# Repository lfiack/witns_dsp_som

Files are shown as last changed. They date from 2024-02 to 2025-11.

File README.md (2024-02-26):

# DSP System on Module from WITNS

## Make the project work
This project uses a submodule for the KiCAD library. To get it properly, use the `--recursive` option when cloning the repo :

```bash
git clone --recursive git@github.com:lfiack/witns_dsp_som
```

If you forgot the `--recursive` option (as I do quite often), you can type the following command :

```bash
git submodule update --init --recursive
```

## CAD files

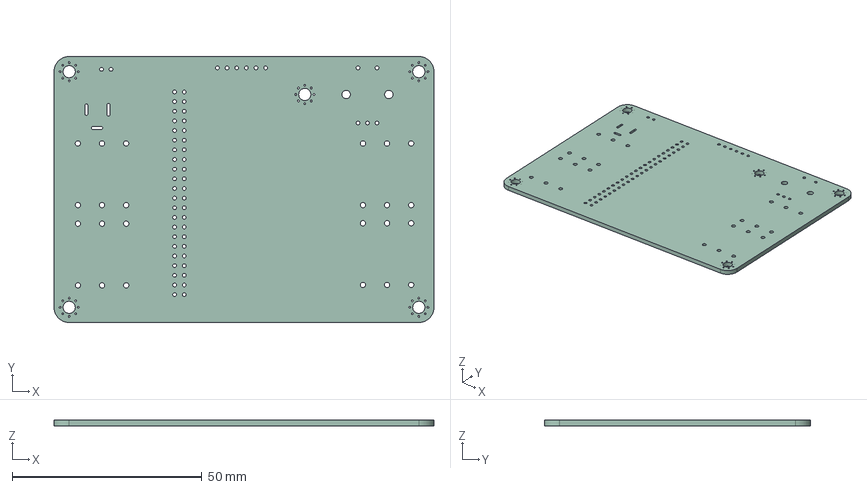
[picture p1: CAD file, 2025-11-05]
hardware/carry/carry/carry.step
100.0 x 70.0 x 1.51 mm

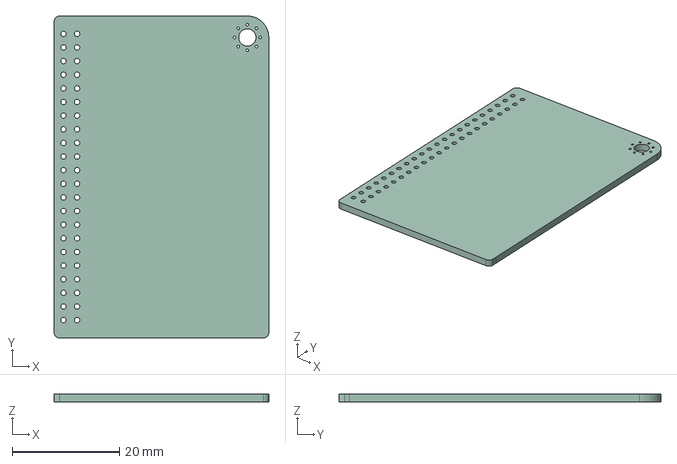
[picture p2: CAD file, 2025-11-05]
hardware/dsp_som/dsp_som.step
40.0 x 60.0 x 1.47 mm

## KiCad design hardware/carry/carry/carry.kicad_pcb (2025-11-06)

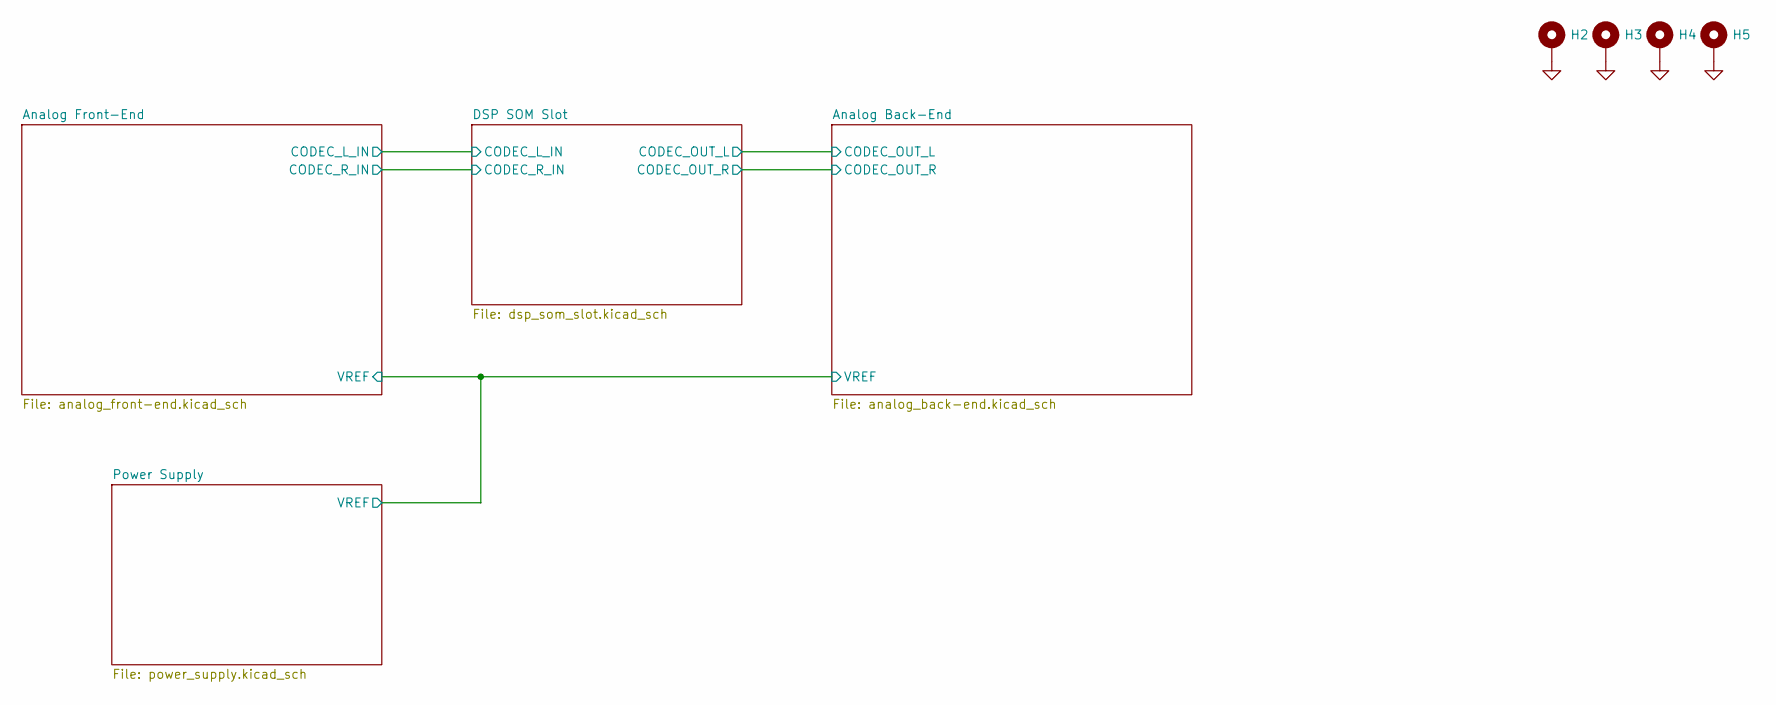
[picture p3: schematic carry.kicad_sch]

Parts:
H2, H3, H4, H5: MountingHole_Pad; MountingHole_3.2mm_M3_Pad_Via

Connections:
GND: H2.1, H3.1, H4.1, H5.1; also elsewhere on the board

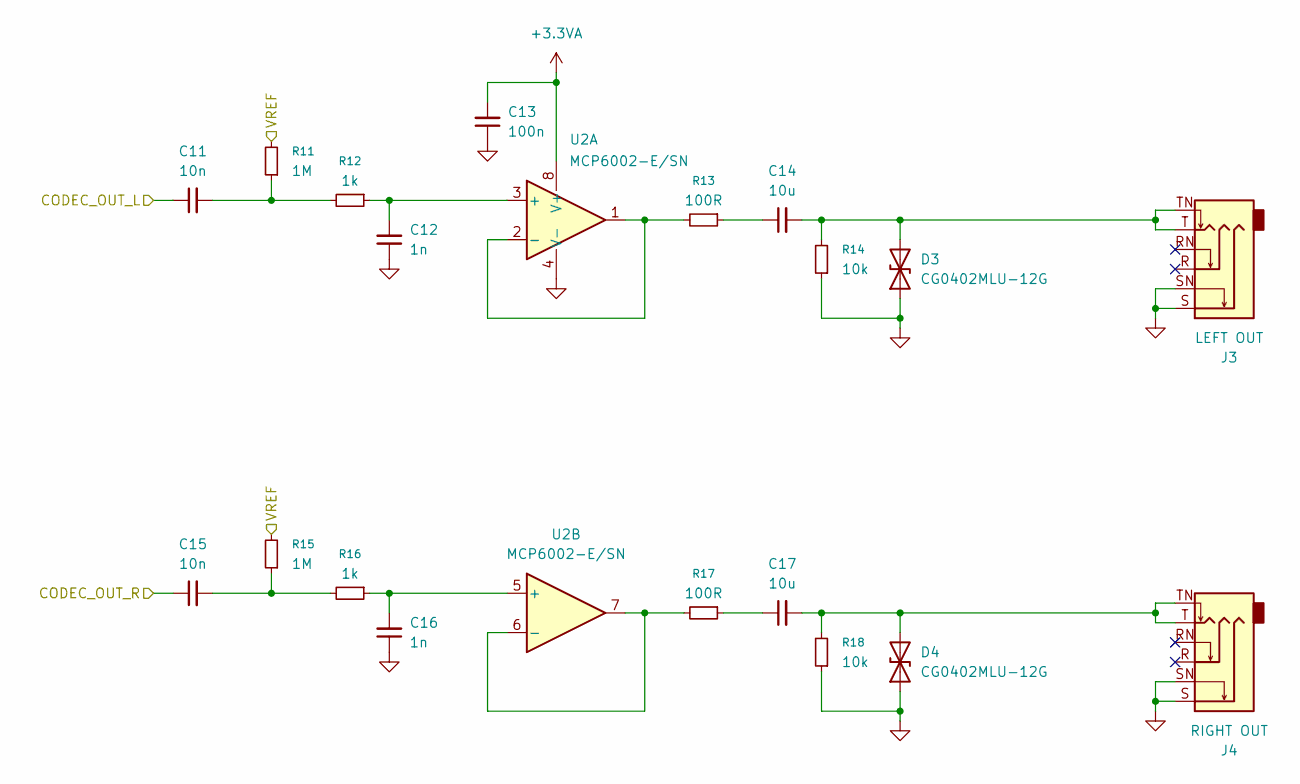
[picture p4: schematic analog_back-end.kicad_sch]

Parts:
C11, C15: 10n; C_0603_1608Metric
C12, C16: 1n; C_0603_1608Metric
C13: 100n; C_0603_1608Metric
C14, C17: 10u; C_0603_1608Metric
D3, D4: CG0402MLU-12G; D_0402_1005Metric
J3: LEFT OUT; Jack_6.35mm_Neutrik_NMJ6HCD3_Horizontal
J4: RIGHT OUT; Jack_6.35mm_Neutrik_NMJ6HCD3_Horizontal
R11, R15: 1M; R_0603_1608Metric
R12, R16: 1k; R_0603_1608Metric
R13, R17: 100R; R_0603_1608Metric
R14, R18: 10k; R_0603_1608Metric
U2: MCP6002-E/SN; SOIC-8_3.9x4.9mm_P1.27mm

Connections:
+3.3VA: C13.2, U2.8 (V+); also elsewhere on the board
/Analog Back-End/CODEC_OUT_L: C11.1; also elsewhere on the board
/Analog Back-End/CODEC_OUT_R: C15.1; also elsewhere on the board
/Analog Back-End/VREF: R11.2, R15.2; also elsewhere on the board
GND: C12.1, C13.1, C16.1, D3.1 (A1), D4.1 (A1), J3.S, J3.SN, J4.S, J4.SN, R14.1, R18.1, U2.4 (V-); also elsewhere on the board
unnamed: C11.2, R11.1, R12.2
unnamed: C14.1, R13.1
unnamed: C15.2, R15.1, R16.2
unnamed: C17.1, R17.1
unnamed: C14.2, D3.2 (A2), J3.T, J3.TN, R14.2
unnamed: C17.2, D4.2 (A2), J4.T, J4.TN, R18.2
unnamed: C12.2, R12.1, U2.3 (+)
unnamed: R13.2, U2.1, U2.2 (-)
unnamed: C16.2, R16.1, U2.5 (+)
unnamed: R17.2, U2.6 (-), U2.7

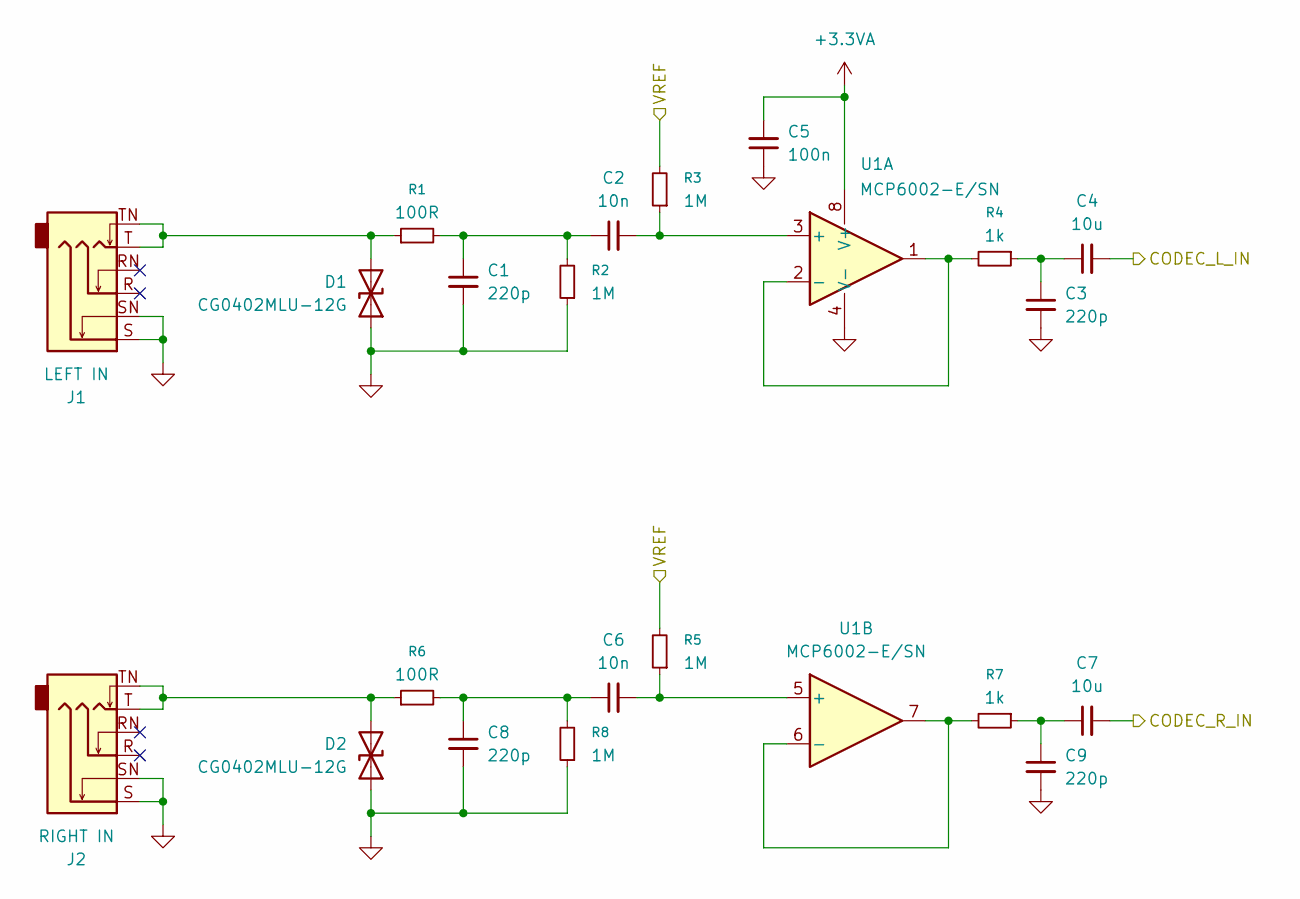
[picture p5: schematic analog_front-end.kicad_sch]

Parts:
C1, C3, C8, C9: 220p; C_0603_1608Metric
C2, C6: 10n; C_0603_1608Metric
C4, C7: 10u; C_0603_1608Metric
C5: 100n; C_0603_1608Metric
D1, D2: CG0402MLU-12G; D_0402_1005Metric
J1: LEFT IN; Jack_6.35mm_Neutrik_NMJ6HCD3_Horizontal
J2: RIGHT IN; Jack_6.35mm_Neutrik_NMJ6HCD3_Horizontal
R1, R6: 100R; R_0603_1608Metric
R2, R3, R5, R8: 1M; R_0603_1608Metric
R4, R7: 1k; R_0603_1608Metric
U1: MCP6002-E/SN; SOIC-8_3.9x4.9mm_P1.27mm

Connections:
+3.3VA: C5.2, U1.8 (V+); also elsewhere on the board
/Analog Back-End/VREF: R3.2, R5.2; also elsewhere on the board
/Analog Front-End/CODEC_L_IN: C4.2; also elsewhere on the board
/Analog Front-End/CODEC_R_IN: C7.2; also elsewhere on the board
GND: C1.2, C3.2, C5.1, C8.2, C9.2, D1.1 (A1), D2.1 (A1), J1.S, J1.SN, J2.S, J2.SN, R2.1, R8.1, U1.4 (V-); also elsewhere on the board
unnamed: C1.1, C2.1, R1.2, R2.2
unnamed: C3.1, C4.1, R4.1
unnamed: C6.1, C8.1, R6.2, R8.2
unnamed: C7.1, C9.1, R7.1
unnamed: D1.2 (A2), J1.T, J1.TN, R1.1
unnamed: D2.2 (A2), J2.T, J2.TN, R6.1
unnamed: C2.2, R3.1, U1.3 (+)
unnamed: R4.2, U1.1, U1.2 (-)
unnamed: C6.2, R5.1, U1.5 (+)
unnamed: R7.2, U1.6 (-), U1.7

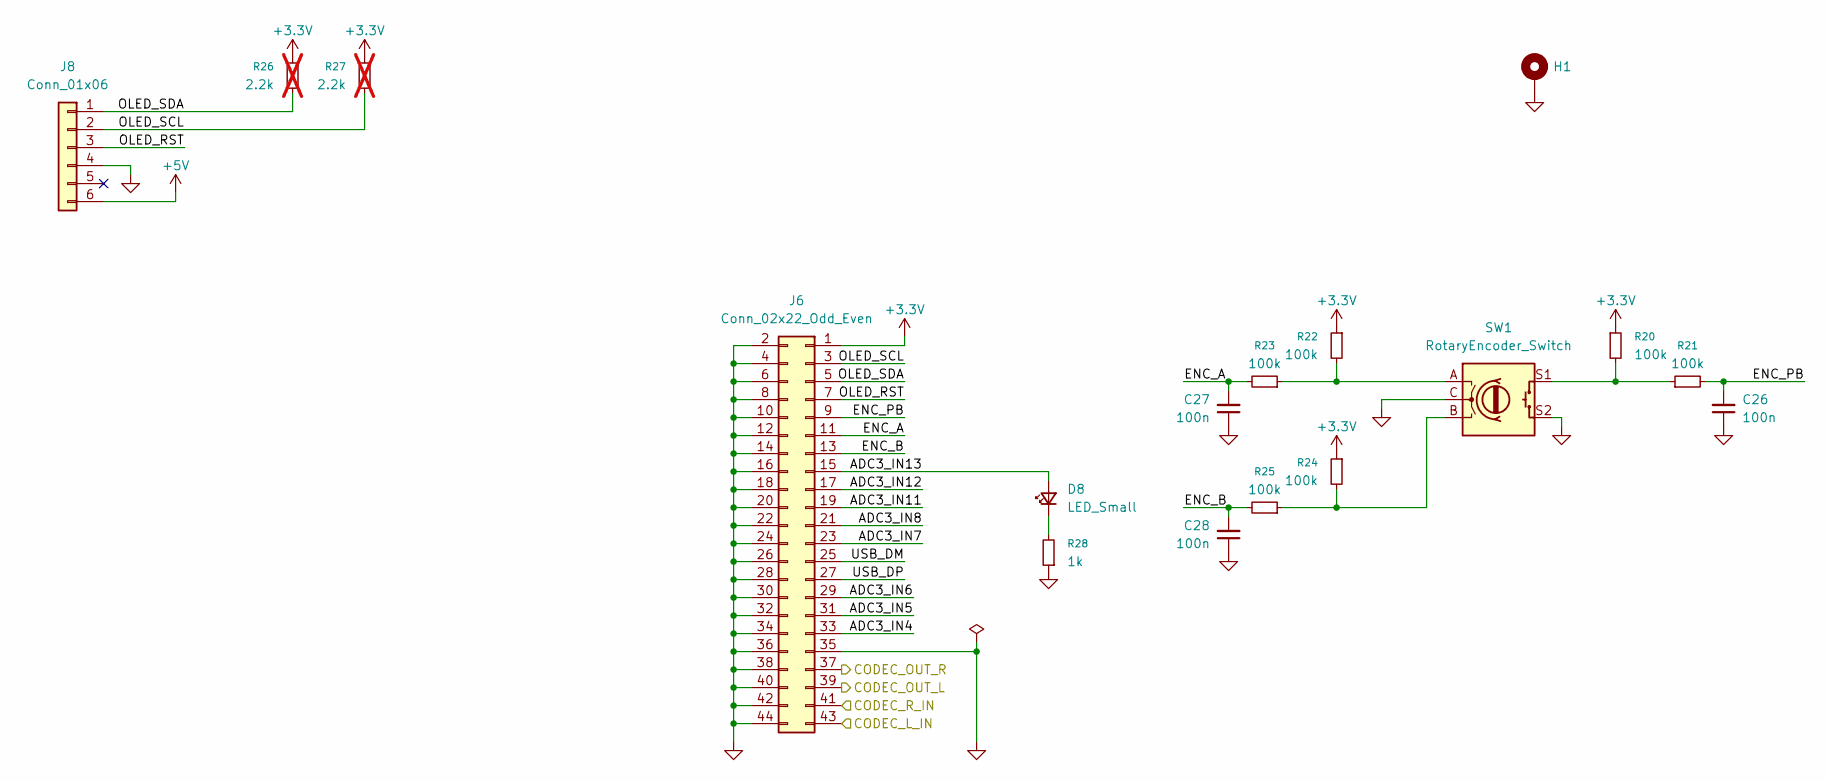
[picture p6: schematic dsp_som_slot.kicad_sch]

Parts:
C26, C27, C28: 100n; C_0603_1608Metric
D8: LED_Small; LED_0603_1608Metric
H1: MountingHole_Pad; MountingHole_3.2mm_M3_Pad_Via
J6: Conn_02x22_Odd_Even; PinSocket_2x22_P2.54mm_Vertical
J8: Conn_01x06; PinSocket_1x06_P2.54mm_Vertical
R20, R21, R22, R23, R24, R25: 100k; R_0603_1608Metric
R26, R27: 2.2k; R_0603_1608Metric; not fitted
R28: 1k; R_0603_1608Metric
SW1: RotaryEncoder_Switch; RotaryEncoder_Alps_EC12E-Switch_Vertical_H20mm_CircularMoun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

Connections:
+3.3V: J6.1, R20.1, R22.1, R24.1, R26.1, R27.1; also elsewhere on the board
+5V: J8.6; also elsewhere on the board
/Analog Back-End/CODEC_OUT_L: J6.39; also elsewhere on the board
/Analog Back-End/CODEC_OUT_R: J6.37; also elsewhere on the board
/Analog Front-End/CODEC_L_IN: J6.43; also elsewhere on the board
/Analog Front-End/CODEC_R_IN: J6.41; also elsewhere on the board
/DSP SOM Slot/ADC3_IN4: J6.33
/DSP SOM Slot/ADC3_IN5: J6.31
/DSP SOM Slot/ADC3_IN6: J6.29
/DSP SOM Slot/ADC3_IN7: J6.23
/DSP SOM Slot/ADC3_IN8: J6.21
/DSP SOM Slot/ADC3_IN11: J6.19
/DSP SOM Slot/ADC3_IN12: J6.17
/DSP SOM Slot/ADC3_IN13: D8.2 (A), J6.15
/DSP SOM Slot/ENC_A: C27.2, J6.11, R23.2
/DSP SOM Slot/ENC_B: C28.2, J6.13, R25.2
/DSP SOM Slot/ENC_PB: C26.2, J6.9, R21.2
/DSP SOM Slot/OLED_RST: J6.7, J8.3
/DSP SOM Slot/OLED_SCL: J6.3, J8.2, R27.2
/DSP SOM Slot/OLED_SDA: J6.5, J8.1, R26.2
/DSP SOM Slot/USB_DM: J6.25
/DSP SOM Slot/USB_DP: J6.27
GND: C26.1, C27.1, C28.1, H1.1, J6.2, J6.4, J6.6, J6.8, J6.10, J6.12, J6.14, J6.16, J6.18, J6.20, J6.22, J6.24, J6.26, J6.28, J6.30, J6.32, J6.34, J6.35, J6.36, J6.38, J6.40, J6.42, J6.44, J8.4, R28.1, SW1.C, SW1.S2; also elsewhere on the board
unnamed: D8.1 (K), R28.2
unnamed: R20.2, R21.1, SW1.S1
unnamed: R22.2, R23.1, SW1.A
unnamed: R24.2, R25.1, SW1.B

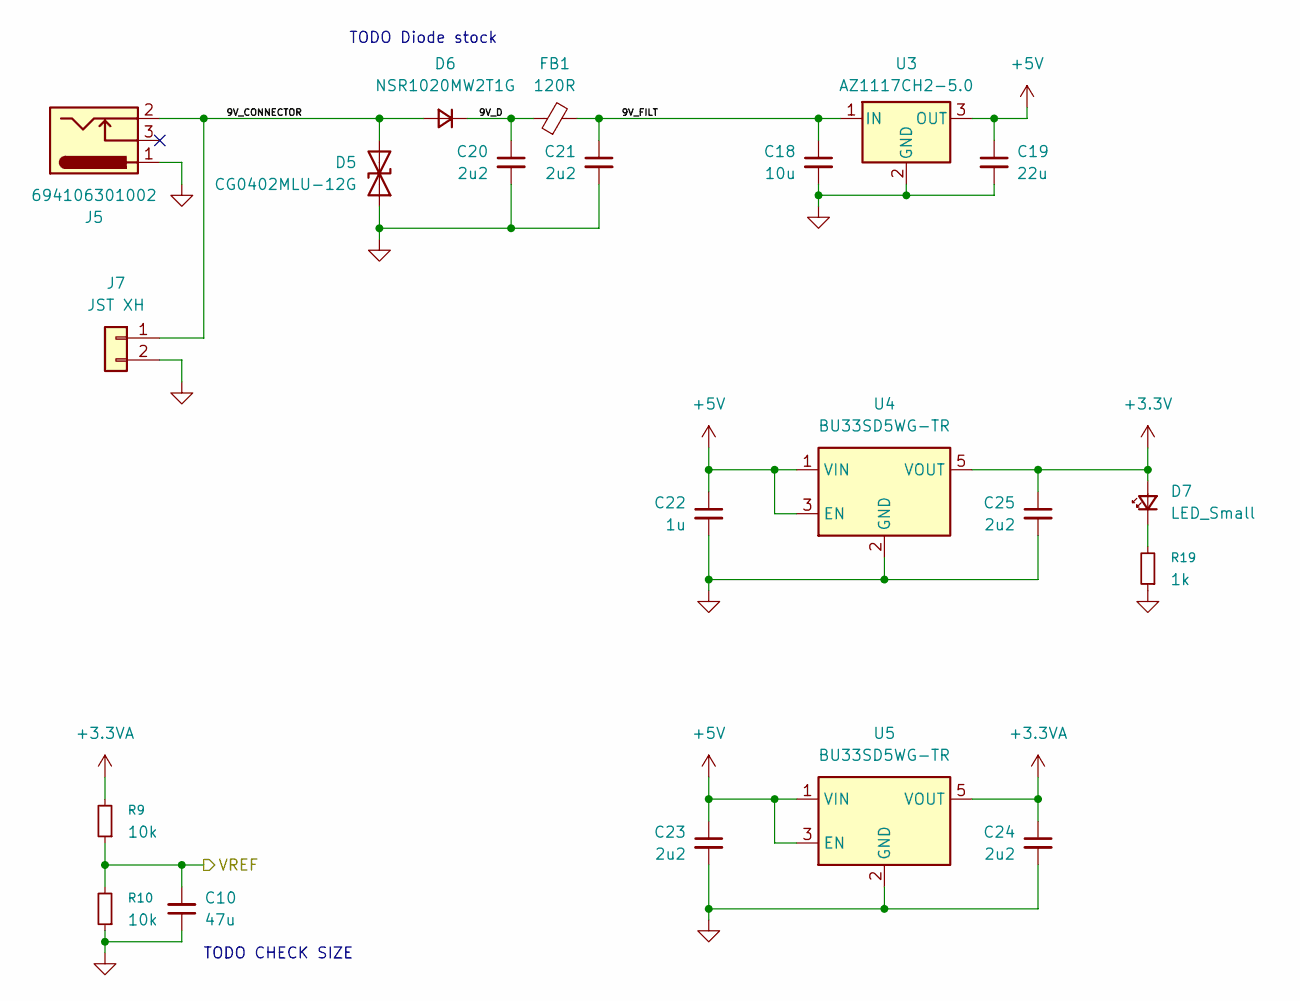
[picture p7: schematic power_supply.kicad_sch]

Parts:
C10: 47u; C_0603_1608Metric
C18: 10u; C_0805_2012Metric
C19: 22u; C_0805_2012Metric
C20, C21, C23, C24, C25: 2u2; C_0603_1608Metric
C22: 1u; C_0603_1608Metric
D5: CG0402MLU-12G; D_0402_1005Metric
D6: NSR1020MW2T1G; D_SOD-323
D7: LED_Small; LED_0603_1608Metric
FB1: 120R; L_0603_1608Metric
J5: 694106301002; BarrelJack_Wuerth_6941xx301002
J7: JST XH; JST_XH_B2B-XH-A_1x02_P2.50mm_Vertical
R9, R10: 10k; R_0603_1608Metric
R19: 1k; R_0603_1608Metric
U3: AZ1117CH2-5.0; SOT-223-3_TabPin2
U4, U5: BU33SD5WG-TR; SOT-23-5

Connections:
+3.3V: C25.1, D7.2 (A), U4.5 (VOUT); also elsewhere on the board
+3.3VA: C24.1, R9.2, U5.5 (VOUT); also elsewhere on the board
+5V: C19.1, C22.1, C23.1, U3.3 (OUT), U4.1 (VIN), U4.3 (EN), U5.1 (VIN), U5.3 (EN); also elsewhere on the board
/Analog Back-End/VREF: C10.2, R9.1, R10.2; also elsewhere on the board
/Power Supply/9V_CONNECTOR: D5.2 (A2), D6.2 (A), J5.2, J7.1
/Power Supply/9V_D: C20.1, D6.1 (K), FB1.1
/Power Supply/9V_FILT: C18.1, C21.1, FB1.2, U3.1 (IN)
GND: C10.1, C18.2, C19.2, C20.2, C21.2, C22.2, C23.2, C24.2, C25.2, D5.1 (A1), J5.1, J7.2, R10.1, R19.1, U3.2 (GND), U4.2 (GND), U5.2 (GND); also elsewhere on the board
unnamed: D7.1 (K), R19.2

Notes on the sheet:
TODO Diode stock
TODO CHECK SIZE

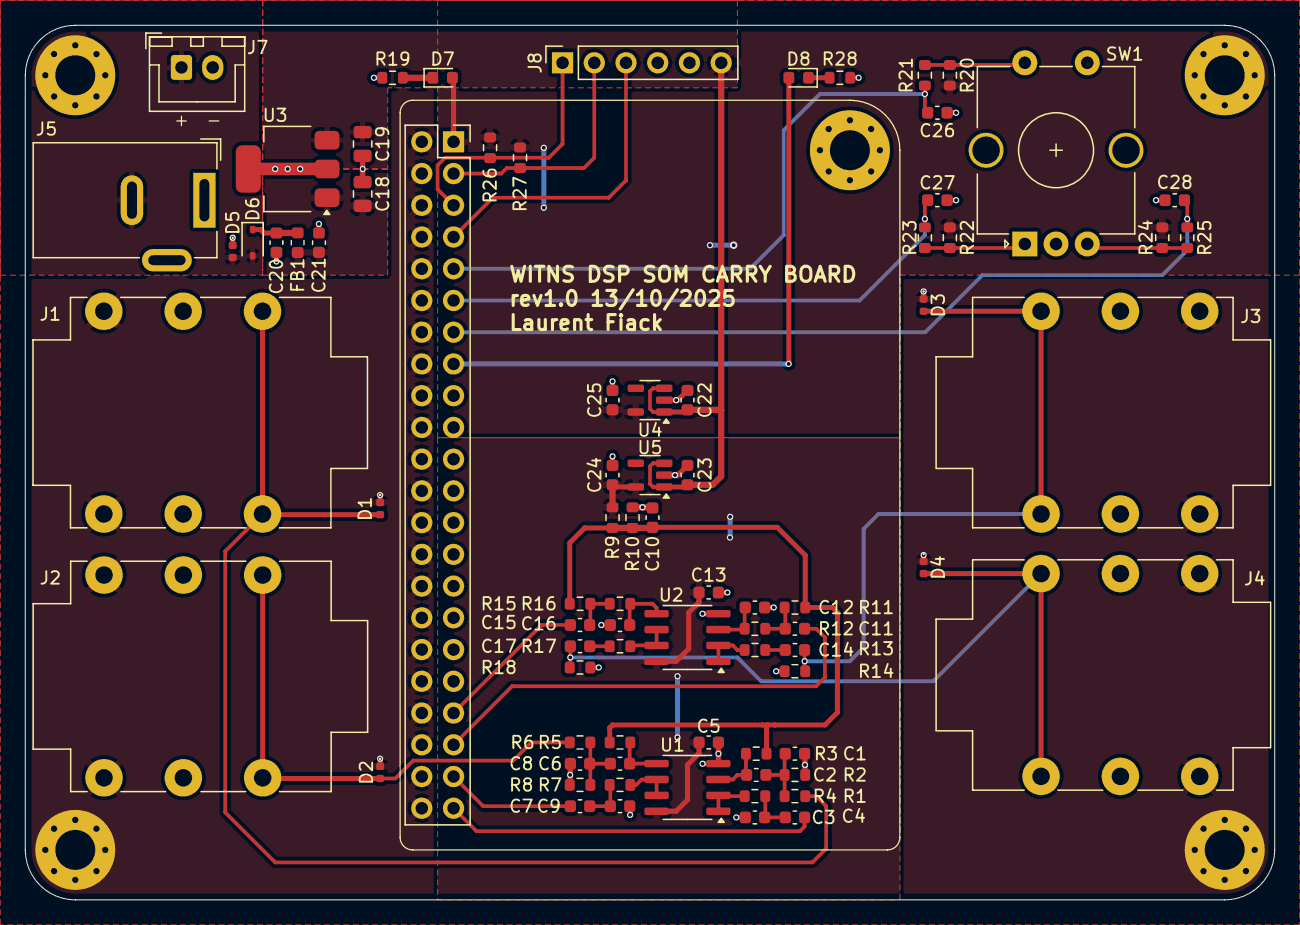
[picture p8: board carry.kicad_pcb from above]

Board: 2 copper layers, 100.0 x 70.0 mm, 84 parts (0 on the bottom side), 44 nets.

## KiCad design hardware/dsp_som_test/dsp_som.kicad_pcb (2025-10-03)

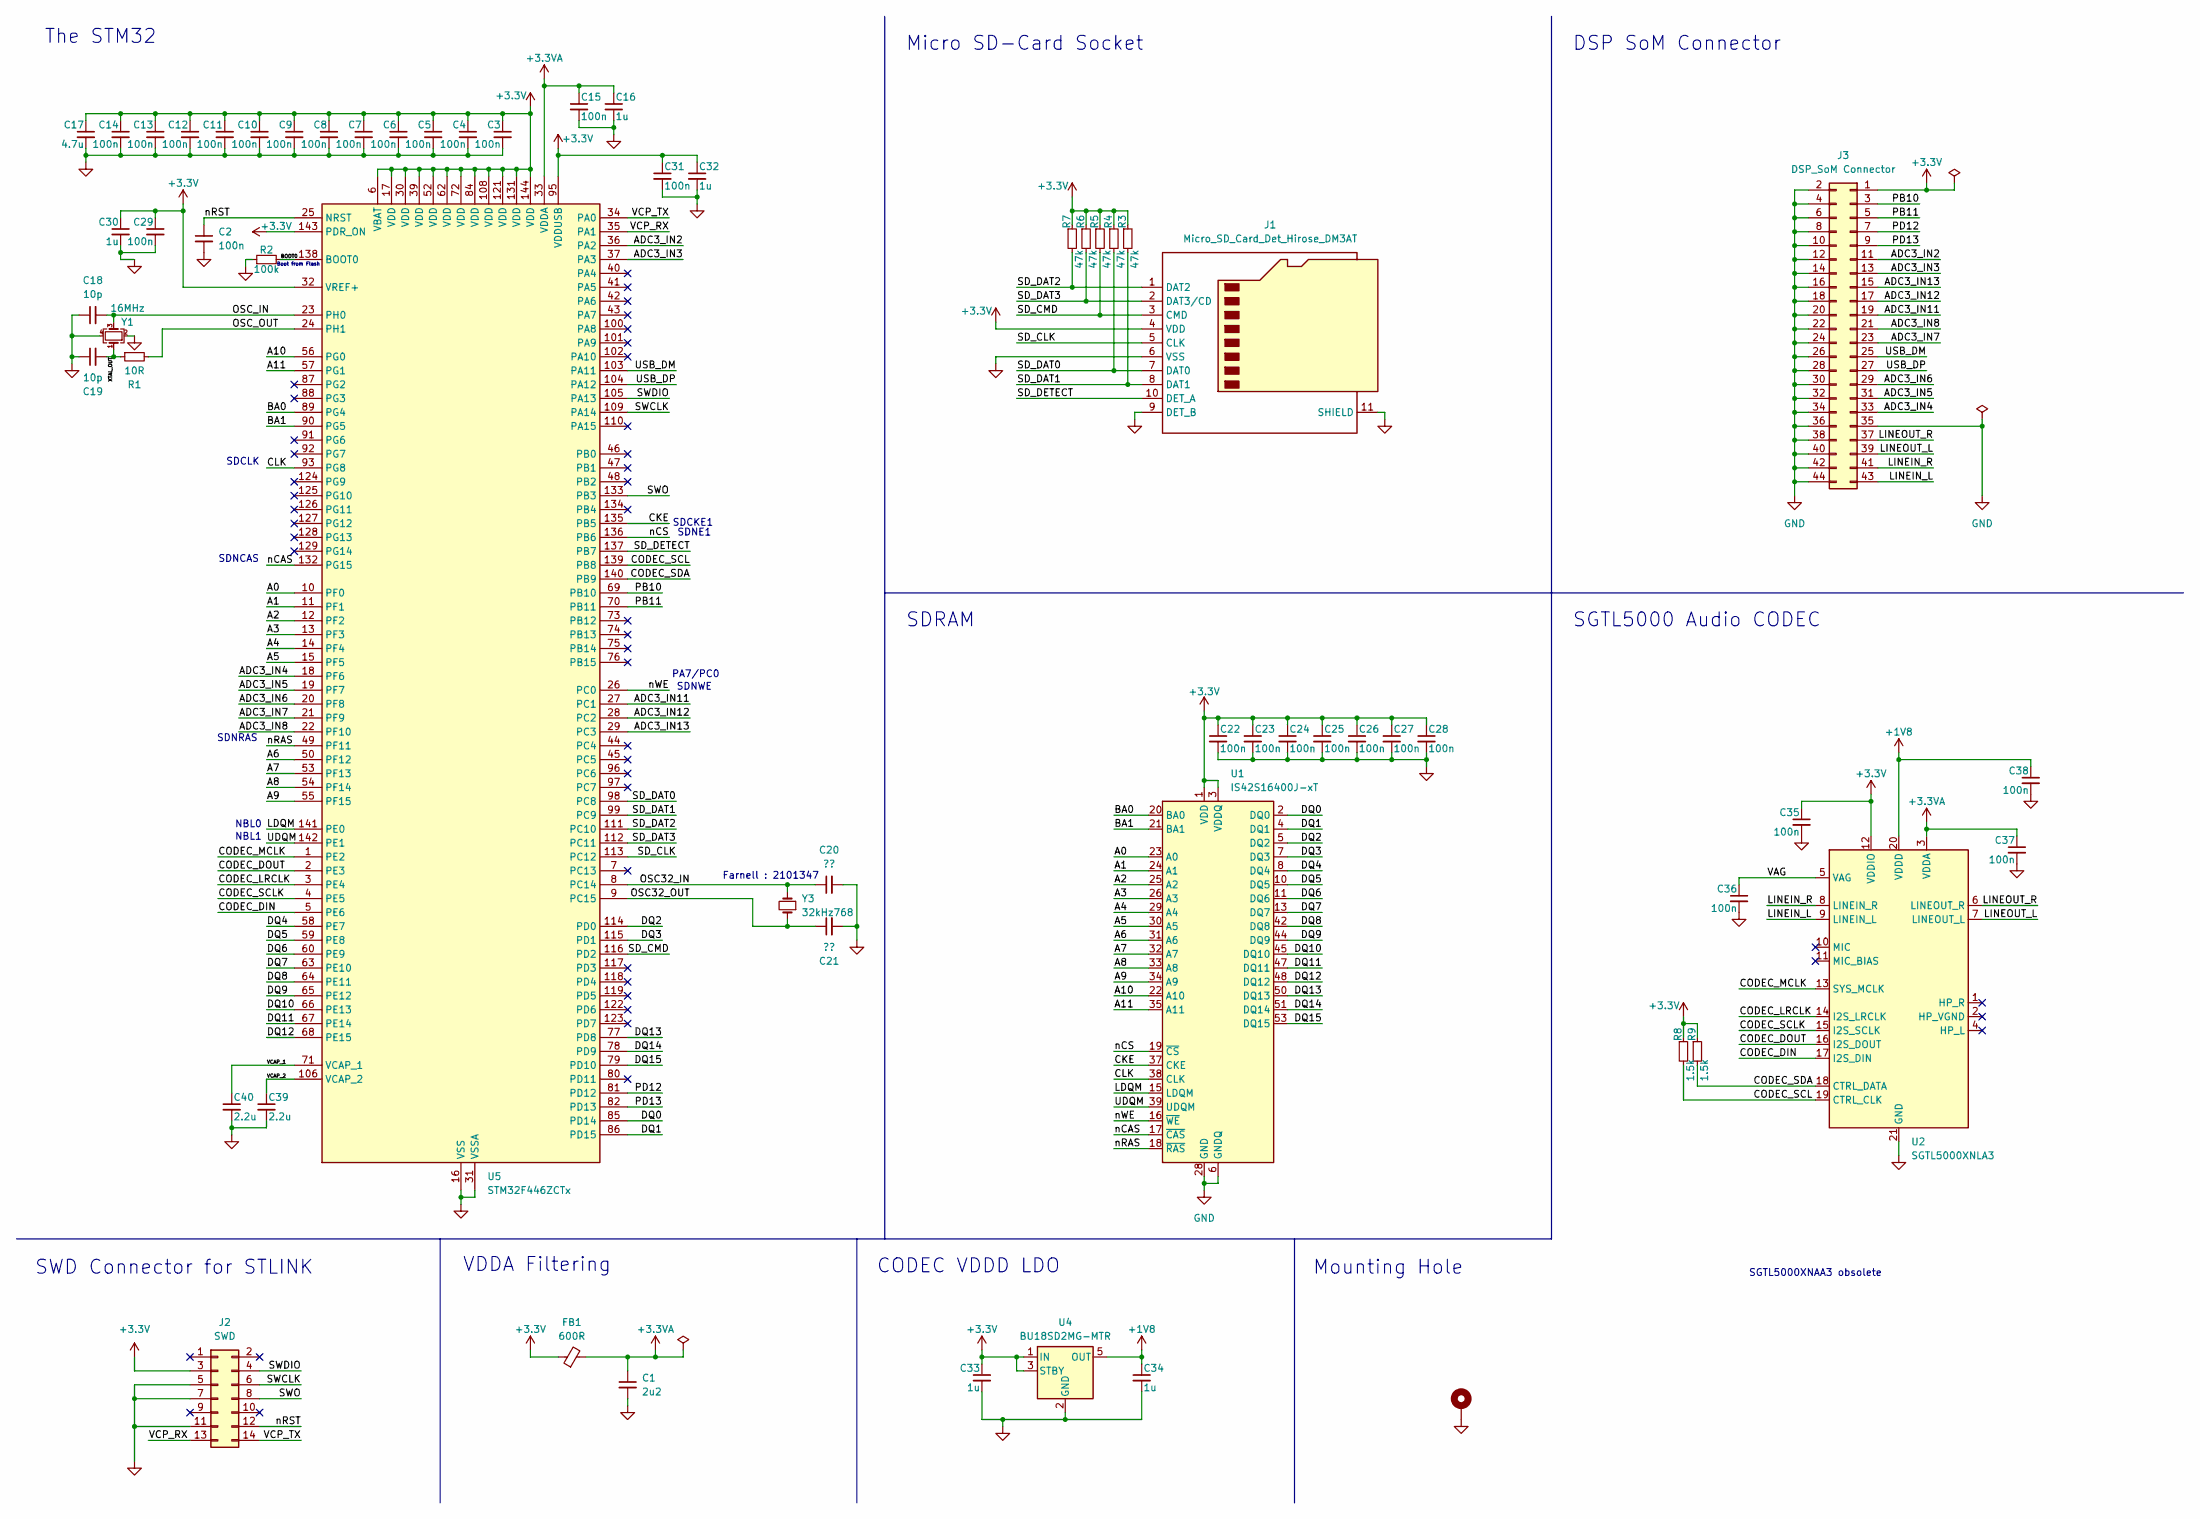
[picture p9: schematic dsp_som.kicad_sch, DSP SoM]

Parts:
C1: 2u2; C_0603_1608Metric
C2, C3, C4, C5, C6, C7, C8, C9, C10, C11, C12, C13, C14, C15, C22, C23, C24, C25, C26, C27, C28, C29, C31, C35, C36, C37, C38: 100n; C_0402_1005Metric
C16, C30, C32, C33, C34: 1u; C_0603_1608Metric
C17: 4.7u; C_0603_1608Metric
C18, C19: 10p; C_0402_1005Metric
C20, C21: ??; C_0402_1005Metric
C39, C40: 2.2u; C_0603_1608Metric
FB1: 600R; L_0603_1608Metric
H1: MountingHole_Pad; MountingHole_3.2mm_M3_Pad_Via
J1: Micro_SD_Card_Det_Hirose_DM3AT; microSD_HC_Hirose_DM3AT-SF-PEJM5
J2: SWD; PinHeader_2x07_P1.27mm_Vertical_SMD
J3: DSP_SoM Connector; PinHeader_2x22_P2.54mm_Vertical
R1: 10R; R_0402_1005Metric
R2: 100k; R_0402_1005Metric
R3, R4, R5, R6, R7: 47k; R_0402_1005Metric
R8, R9: 1.5k; R_0402_1005Metric
U1: IS42S16400J-xT; TSOP-II-54_22.2x10.16mm_P0.8mm
U2: SGTL5000XNLA3; QFN-20-1EP_3x3mm_P0.4mm_EP1.65x1.65mm
U4: BU18SD2MG-MTR; SOT-23-5
U5: STM32F446ZCTx; LQFP-144_20x20mm_P0.5mm
Y1: 16MHz; Crystal_SMD_EuroQuartz_MT-4Pin_3.2x2.5mm; Farnell 2853935
Y3: 32kHz768; Crystal_SMD_3215-2Pin_3.2x1.5mm

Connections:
+1V8: C34.1, C38.1, U2.20 (VDDD), U4.5 (OUT)
+3.3V: C3.1, C4.1, C5.1, C6.1, C7.1, C8.1, C9.1, C10.1, C11.1, C12.1, C13.1, C14.1, C17.1, C22.1, C23.1, C24.1, C25.1, C26.1, C27.1, C28.1, C29.1, C30.1, C31.1, C32.1, C33.1, C35.1, FB1.1, J1.4 (VDD), J2.3, J3.1, R3.1, R4.1, R5.1, R6.1, R7.1, R8.1, R9.1, U1.1 (VDD), U1.3 (VDDQ), U1.9 (VDDQ), U1.14 (VDD), U1.27 (VDD), U1.43 (VDDQ), U1.49 (VDDQ), U2.12 (VDDIO), U4.1 (IN), U4.3 (STBY), U5.6 (VBAT), U5.17 (VDD), U5.30 (VDD), U5.32 (VREF+), U5.39 (VDD), U5.52 (VDD), U5.62 (VDD), U5.72 (VDD), U5.84 (VDD), U5.95 (VDDUSB), U5.108 (VDD), U5.121 (VDD), U5.131 (VDD), U5.143 (PDR_ON), U5.144 (VDD)
+3.3VA: C1.1, C15.1, C16.1, C37.1, FB1.2, U2.3 (VDDA), U5.33 (VDDA)
/A0: U1.23 (A0), U5.10 (PF0)
/A1: U1.24 (A1), U5.11 (PF1)
/A2: U1.25 (A2), U5.12 (PF2)
/A3: U1.26 (A3), U5.13 (PF3)
/A4: U1.29 (A4), U5.14 (PF4)
/A5: U1.30 (A5), U5.15 (PF5)
/A6: U1.31 (A6), U5.50 (PF12)
/A7: U1.32 (A7), U5.53 (PF13)
/A8: U1.33 (A8), U5.54 (PF14)
/A9: U1.34 (A9), U5.55 (PF15)
/A10: U1.22 (A10), U5.56 (PG0)
/A11: U1.35 (A11), U5.57 (PG1)
/ADC3_IN2: J3.11, U5.36 (PA2)
/ADC3_IN3: J3.13, U5.37 (PA3)
/ADC3_IN4: J3.33, U5.18 (PF6)
/ADC3_IN5: J3.31, U5.19 (PF7)
/ADC3_IN6: J3.29, U5.20 (PF8)
/ADC3_IN7: J3.23, U5.21 (PF9)
/ADC3_IN8: J3.21, U5.22 (PF10)
/ADC3_IN11: J3.19, U5.27 (PC1)
/ADC3_IN12: J3.17, U5.28 (PC2)
/ADC3_IN13: J3.15, U5.29 (PC3)
/BA0: U1.20 (BA0), U5.89 (PG4)
/BA1: U1.21 (BA1), U5.90 (PG5)
/BOOT0: R2.2, U5.138 (BOOT0)
/CKE: U1.37 (CKE), U5.135 (PB5)
/CLK: U1.38 (CLK), U5.93 (PG8)
/CODEC_DIN: U2.17 (I2S_DIN), U5.5 (PE6)
/CODEC_DOUT: U2.16 (I2S_DOUT), U5.2 (PE3)
/CODEC_LRCLK: U2.14 (I2S_LRCLK), U5.3 (PE4)
/CODEC_MCLK: U2.13 (SYS_MCLK), U5.1 (PE2)
/CODEC_SCL: R8.2, U2.19 (CTRL_CLK), U5.139 (PB8)
/CODEC_SCLK: U2.15 (I2S_SCLK), U5.4 (PE5)
/CODEC_SDA: R9.2, U2.18 (CTRL_DATA), U5.140 (PB9)
/DQ0: U1.2 (DQ0), U5.85 (PD14)
/DQ1: U1.4 (DQ1), U5.86 (PD15)
/DQ2: U1.5 (DQ2), U5.114 (PD0)
/DQ3: U1.7 (DQ3), U5.115 (PD1)
/DQ4: U1.8 (DQ4), U5.58 (PE7)
/DQ5: U1.10 (DQ5), U5.59 (PE8)
/DQ6: U1.11 (DQ6), U5.60 (PE9)
/DQ7: U1.13 (DQ7), U5.63 (PE10)
/DQ8: U1.42 (DQ8), U5.64 (PE11)
/DQ9: U1.44 (DQ9), U5.65 (PE12)
/DQ10: U1.45 (DQ10), U5.66 (PE13)
/DQ11: U1.47 (DQ11), U5.67 (PE14)
/DQ12: U1.48 (DQ12), U5.68 (PE15)
/DQ13: U1.50 (DQ13), U5.77 (PD8)
/DQ14: U1.51 (DQ14), U5.78 (PD9)
/DQ15: U1.53 (DQ15), U5.79 (PD10)
/LDQM: U1.15 (LDQM), U5.141 (PE0)
/LINEIN_L: J3.43, U2.9 (LINEIN_L)
/LINEIN_R: J3.41, U2.8 (LINEIN_R)
/LINEOUT_L: J3.39, U2.7 (LINEOUT_L)
/LINEOUT_R: J3.37, U2.6 (LINEOUT_R)
/OSC32_IN: C20.1, U5.8 (PC14), Y3.2
/OSC32_OUT: C21.1, U5.9 (PC15), Y3.1
/OSC_IN: C18.2, U5.23 (PH0), Y1.3
/OSC_OUT: R1.2, U5.24 (PH1)
/PB10: J3.3, U5.69 (PB10)
/PB11: J3.5, U5.70 (PB11)
/PD12: J3.7, U5.81 (PD12)
/PD13: J3.9, U5.82 (PD13)
/SD_CLK: J1.5 (CLK), U5.113 (PC12)
/SD_CMD: J1.3 (CMD), R5.2, U5.116 (PD2)
/SD_DAT0: J1.7 (DAT0), R4.2, U5.98 (PC8)
/SD_DAT1: J1.8 (DAT1), R3.2, U5.99 (PC9)
/SD_DAT2: J1.1 (DAT2), R7.2, U5.111 (PC10)
/SD_DAT3: J1.2 (DAT3/CD), R6.2, U5.112 (PC11)
/SD_DETECT: J1.10 (DET_A), U5.137 (PB7)
/SWCLK: J2.6, U5.109 (PA14)
/SWDIO: J2.4, U5.105 (PA13)
/SWO: J2.8, U5.133 (PB3)
/UDQM: U1.39 (UDQM), U5.142 (PE1)
/USB_DM: J3.25, U5.103 (PA11)
/USB_DP: J3.27, U5.104 (PA12)
/VAG: C36.1, U2.5 (VAG)
/VCAP_1: C40.1, U5.71 (VCAP_1)
/VCAP_2: C39.1, U5.106 (VCAP_2)
/VCP_RX: J2.13, U5.35 (PA1)
/VCP_TX: J2.14, U5.34 (PA0)
/XTAL_OUT: C19.2, R1.1, Y1.1
/nCAS: U1.17 (~CAS), U5.132 (PG15)
/nCS: U1.19 (~CS), U5.136 (PB6)
/nRAS: U1.18 (~RAS), U5.49 (PF11)
/nRST: C2.1, J2.12, U5.25 (NRST)
/nWE: U1.16 (~WE), U5.26 (PC0)
GND: C1.2, C2.2, C3.2, C4.2, C5.2, C6.2, C7.2, C8.2, C9.2, C10.2, C11.2, C12.2, C13.2, C14.2, C15.2, C16.2, C17.2, C18.1, C19.1, C20.2, C21.2, C22.2, C23.2, C24.2, C25.2, C26.2, C27.2, C28.2, C29.2, C30.2, C31.2, C32.2, C33.2, C34.2, C35.2, C36.2, C37.2, C38.2, C39.2, C40.2, H1.1, J1.6 (VSS), J1.9 (DET_B), J1.11 (SHIELD), J2.5, J2.7, J2.11, J3.2, J3.4, J3.6, J3.8, J3.10, J3.12, J3.14, J3.16, J3.18, J3.20, J3.22, J3.24, J3.26, J3.28, J3.30, J3.32, J3.34, J3.35, J3.36, J3.38, J3.40, J3.42, J3.44, R2.1, U1.6 (GNDQ), U1.12 (GNDQ), U1.28 (GND), U1.41 (GND), U1.46 (GNDQ), U1.52 (GNDQ), U1.54 (GND), U2.21 (GND), U4.2 (GND), U5.16 (VSS), U5.31 (VSSA), U5.38 (VSS), U5.51 (VSS), U5.61 (VSS), U5.83 (VSS), U5.94 (VSS), U5.107 (VSS), U5.120 (VSS), U5.130 (VSS), Y1.2, Y1.4

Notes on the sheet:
Mounting Hole
NBL0
SDCLK
CODEC VDDD LDO
SGTL5000 Audio CODEC
Boot from Flash
Farnell : 2101347
SGTL5000XNAA3 obsolete
Micro SD-Card Socket
NBL1
PA7/PC0
SDNCAS
SDNRAS
SDRAM
SDNWE
VDDA Filtering
The STM32
SDNE1
SWD Connector for STLINK
DSP SoM Connector
SDCKE1

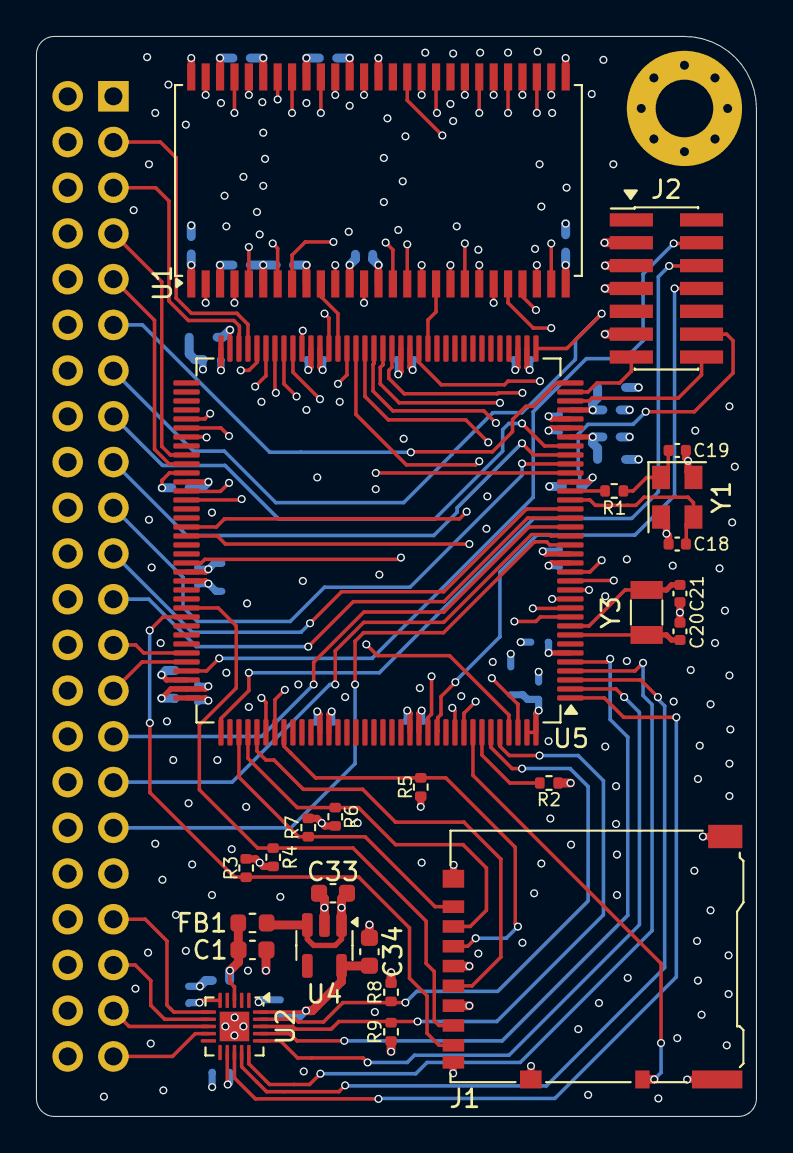
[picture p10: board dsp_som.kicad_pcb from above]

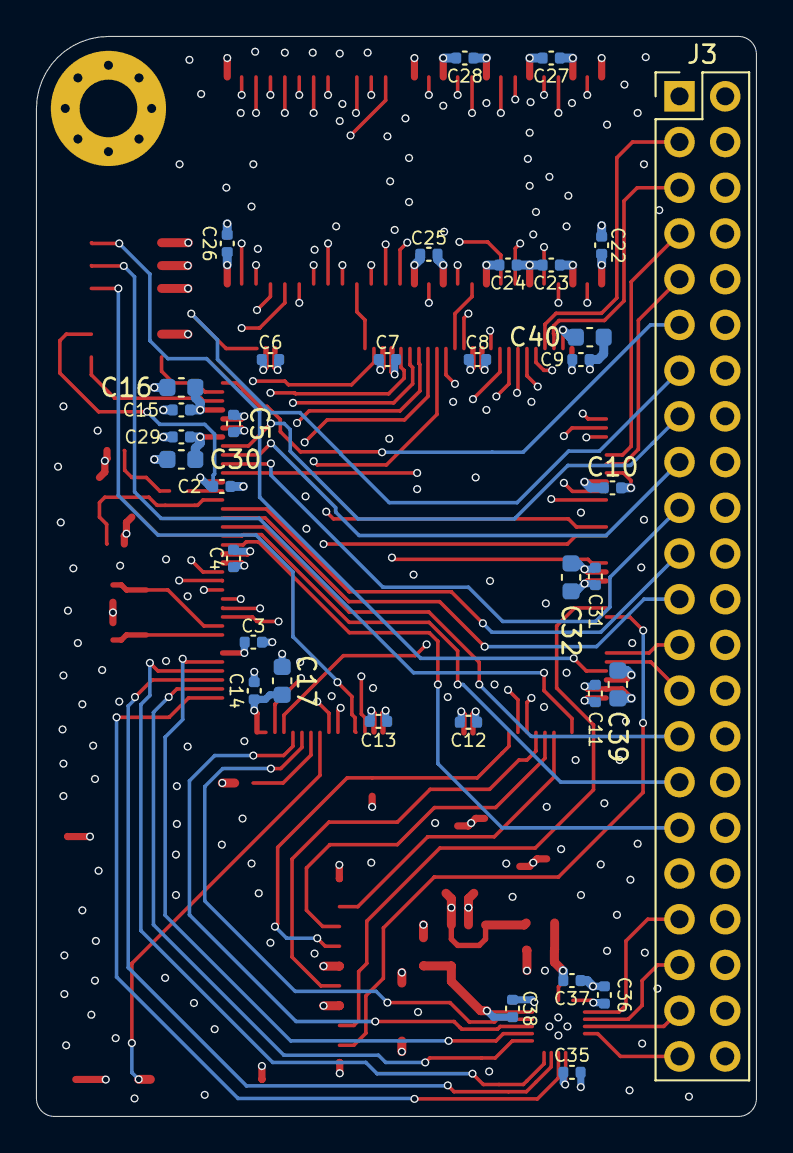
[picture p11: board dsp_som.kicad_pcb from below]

Board: 6 copper layers, 40.0 x 60.0 mm, 60 parts (34 on the bottom side), 91 nets.

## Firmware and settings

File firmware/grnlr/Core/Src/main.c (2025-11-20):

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
/* Includes ------------------------------------------------------------------*/
#include "main.h"
#include "cmsis_os.h"
#include "adc.h"
#include "dma.h"
#include "fatfs.h"
#include "i2c.h"
#include "sai.h"
#include "sdio.h"
#include "tim.h"
#include "usart.h"
#include "usb_otg.h"
#include "gpio.h"
#include "fmc.h"

/* USER CODE BEGIN Includes */
#include <stdio.h>

#include "app.h"
#include "coder.h"
#include "ssd1306.h"
/* USER CODE END Includes */


/* USER CODE BEGIN PV */
#define __sdram __attribute__((section(".sdram_data")))

// #define AUDIO_BUFFER_LENGTH 2097152	// 8MB
// __sdram uint32_t audio_buffer[AUDIO_BUFFER_LENGTH];
/* USER CODE END PV */

void SystemClock_Config(void);
void PeriphCommonClock_Config(void);
void MX_FREERTOS_Init(void);
/* USER CODE BEGIN 0 */


void HAL_GPIO_EXTI_Callback(uint16_t GPIO_Pin)
{
	switch(GPIO_Pin)
	{
		case ENC_PB_Pin:
			coder_pb_pressed_cb(&h_coder);
			break;
		case ENC_A_Pin:
			if (HAL_GPIO_ReadPin(ENC_A_GPIO_Port, ENC_A_Pin) != HAL_GPIO_ReadPin(ENC_B_GPIO_Port, ENC_B_Pin))
			{
				coder_increment_cb(&h_coder, 1);
			}
			if (HAL_GPIO_ReadPin(ENC_A_GPIO_Port, ENC_A_Pin) == HAL_GPIO_ReadPin(ENC_B_GPIO_Port, ENC_B_Pin))
			{
				coder_increment_cb(&h_coder, -1);
			}

			break;
		case ENC_B_Pin:
			break;
		default:
			break;
	}
}

void HAL_SAI_TxHalfCpltCallback(SAI_HandleTypeDef *hsai)
{
	if (SAI1_Block_A == hsai->Instance)
	{
		// Nothing for now
	}
}

void HAL_SAI_TxCpltCallback(SAI_HandleTypeDef *hsai)
{
	if (SAI1_Block_A == hsai->Instance)
	{
		// Nothing for now
	}
}

void HAL_SAI_RxHalfCpltCallback(SAI_HandleTypeDef *hsai)
{
	if (SAI1_Block_B == hsai->Instance)
	{
		h_stats.period = __HAL_TIM_GET_COUNTER(&htim6);
		__HAL_TIM_SET_COUNTER(&htim6, 0);

		//process first half of h_sgtl5000 buffer
		app_process_audio(
				h_sgtl5000.sai_rx_buffer, 
				h_sgtl5000.sai_tx_buffer, 
				AUDIO_BUFFER_LENGTH * AUDIO_NUM_CHANNELS
				);

		h_stats.duration = __HAL_TIM_GET_COUNTER(&htim6);
	}
}

void HAL_SAI_RxCpltCallback(SAI_HandleTypeDef *hsai)
{
	if (SAI1_Block_B == hsai->Instance)
	{
		h_stats.period = __HAL_TIM_GET_COUNTER(&htim6);
		__HAL_TIM_SET_COUNTER(&htim6, 0);

		//process second half of h_sgtl5000 buffer
		app_process_audio(
				&h_sgtl5000.sai_rx_buffer[AUDIO_BUFFER_LENGTH * AUDIO_NUM_CHANNELS], 
				&h_sgtl5000.sai_tx_buffer[AUDIO_BUFFER_LENGTH * AUDIO_NUM_CHANNELS], 
				AUDIO_BUFFER_LENGTH * AUDIO_NUM_CHANNELS
				);

		h_stats.duration = __HAL_TIM_GET_COUNTER(&htim6);
	}
}

void HAL_I2C_MemTxCpltCallback(I2C_HandleTypeDef *hi2c)
{
	if (I2C2 == hi2c->Instance)
	{
		ssd1306_i2c_mem_write_cb();
	}
}

#define SDRAM_MODEREG_BURST_LENGTH_1             ((uint16_t)0x0000)
#define SDRAM_MODEREG_BURST_LENGTH_2             ((uint16_t)0x0001)
#define SDRAM_MODEREG_BURST_LENGTH_4             ((uint16_t)0x0002)
#define SDRAM_MODEREG_BURST_LENGTH_8             ((uint16_t)0x0004)
#define SDRAM_MODEREG_BURST_TYPE_SEQUENTIAL      ((uint16_t)0x0000)
#define SDRAM_MODEREG_BURST_TYPE_INTERLEAVED     ((uint16_t)0x0008)
#define SDRAM_MODEREG_CAS_LATENCY_2              ((uint16_t)0x0020)
#define SDRAM_MODEREG_CAS_LATENCY_3              ((uint16_t)0x0030)
#define SDRAM_MODEREG_OPERATING_MODE_STANDARD    ((uint16_t)0x0000)
#define SDRAM_MODEREG_WRITEBURST_MODE_PROGRAMMED ((uint16_t)0x0000)
#define SDRAM_MODEREG_WRITEBURST_MODE_SINGLE     ((uint16_t)0x0200)

static HAL_StatusTypeDef SDRAM_Initialization_Sequence(SDRAM_HandleTypeDef *hsdram)
{
	HAL_StatusTypeDef ret;
	FMC_SDRAM_CommandTypeDef command;
	__IO uint32_t tmpmrd =0;
	/* Step 3:  Configure a clock configuration enable command */
	command.CommandMode 			 = FMC_SDRAM_CMD_CLK_ENABLE;
	command.CommandTarget 		 = FMC_SDRAM_CMD_TARGET_BANK2;
	command.AutoRefreshNumber 	 = 1;
	command.ModeRegisterDefinition = 0;

	/* Send the command */
	ret = HAL_SDRAM_SendCommand(hsdram, &command, 0x1000);
	if (ret != HAL_OK)
	{
		return ret;
	}

	/* Step 4: Insert 100 ms delay */
	HAL_Delay(100);

	/* Step 5: Configure a PALL (precharge all) command */
	command.CommandMode 			 = FMC_SDRAM_CMD_PALL;
	command.CommandTarget 	     = FMC_SDRAM_CMD_TARGET_BANK2;
	command.AutoRefreshNumber 	 = 1;
	command.ModeRegisterDefinition = 0;

	/* Send the command */
	ret = HAL_SDRAM_SendCommand(hsdram, &command, 0x1000);
	if (ret != HAL_OK)
	{
		return ret;
	}


	/* Step 6 : Configure a Auto-Refresh command */
	command.CommandMode 			 = FMC_SDRAM_CMD_AUTOREFRESH_MODE;
	command.CommandTarget 		 = FMC_SDRAM_CMD_TARGET_BANK2;
	command.AutoRefreshNumber 	 = 4;
	command.ModeRegisterDefinition = 0;

	/* Send the command */
	ret = HAL_SDRAM_SendCommand(hsdram, &command, 0x1000);
	if (ret != HAL_OK)
	{
		return ret;
	}


	/* Step 7: Program the external memory mode register */
	tmpmrd = (uint32_t)SDRAM_MODEREG_BURST_LENGTH_2          |
		SDRAM_MODEREG_BURST_TYPE_SEQUENTIAL   |
		SDRAM_MODEREG_CAS_LATENCY_3           |
		SDRAM_MODEREG_OPERATING_MODE_STANDARD |
		SDRAM_MODEREG_WRITEBURST_MODE_SINGLE;

	command.CommandMode = FMC_SDRAM_CMD_LOAD_MODE;
	command.CommandTarget 		 = FMC_SDRAM_CMD_TARGET_BANK2;
	command.AutoRefreshNumber 	 = 1;
	command.ModeRegisterDefinition = tmpmrd;

	/* Send the command */
	ret = HAL_SDRAM_SendCommand(hsdram, &command, 0x1000);
	if (ret != HAL_OK)
	{
		return ret;
	}

	/* Step 8: Set the refresh rate counter */
	/* (15.62 us x Freq) - 20 */
	/* (15.62 * 180) - 20 = 2792 */
	/* Set the device refresh counter */
	return HAL_SDRAM_ProgramRefreshRate(hsdram, 2792);
	// was 0x056A for 90MHz
}

uint32_t sdram_test(uint32_t* buffer, uint32_t size)
{
	uint32_t fail = 0;
	uint32_t tick = HAL_GetTick();
	for (uint32_t i = 0 ; i < size ; i++)
	{
		buffer[i] = i;
	}
	uint32_t new_tick = HAL_GetTick();
	printf("8MB written in %lu ms\r\n", new_tick - tick);
	tick = HAL_GetTick();
	for (uint32_t i = 0 ; i < size ; i++)
	{
		if (buffer[i] != i)
		{
			fail++;
		}
	}
	new_tick = HAL_GetTick();
	printf("8MB read in %lu ms\r\n", new_tick - tick);
	return fail;
}
/* USER CODE END 0 */

/**
  * @brief  The application entry point.
  * @retval int
  */
int main(void)
{

  /* MCU Configuration--------------------------------------------------------*/

  /* Reset of all peripherals, Initializes the Flash interface and the Systick. */
  HAL_Init();

  /* Configure the system clock */
  SystemClock_Config();

  /* Configure the peripherals common clocks */
  PeriphCommonClock_Config();

  /* Initialize all configured peripherals */
  MX_GPIO_Init();
  MX_DMA_Init();
  MX_FMC_Init();
  MX_ADC3_Init();
  MX_I2C1_Init();
  MX_SAI1_Init();
  MX_SDIO_SD_Init();
  MX_UART4_Init();
  MX_USB_OTG_FS_PCD_Init();
  MX_FATFS_Init();
  MX_I2C2_Init();
  MX_TIM6_Init();
  MX_TIM2_Init();
  /* USER CODE BEGIN 2 */
	if (SDRAM_Initialization_Sequence(&hsdram1) != HAL_OK)
	{
		printf("failed to initialize SDRAM\r\n");
	}

	// app_init();

	// app_process();
  /* USER CODE END 2 */

  /* Init scheduler */
  osKernelInitialize();  /* Call init function for freertos objects (in cmsis_os2.c) */
  MX_FREERTOS_Init();

  /* Start scheduler */
  osKernelStart();

  /* We should never get here as control is now taken by the scheduler */

  /* Infinite loop */
  /* USER CODE BEGIN WHILE */

	while (1)
	{
    /* USER CODE END WHILE */

    /* USER CODE BEGIN 3 */
	}
  /* USER CODE END 3 */
}

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
/**
  * @brief  Period elapsed callback in non blocking mode
  * @note   This function is called  when TIM7 interrupt took place, inside
  * HAL_TIM_IRQHandler(). It makes a direct call to HAL_IncTick() to increment
  * a global variable "uwTick" used as application time base.
  * @param  htim : TIM handle
  * @retval None
  */
void HAL_TIM_PeriodElapsedCallback(TIM_HandleTypeDef *htim)
{
  if (htim->Instance == TIM7)
  {
    HAL_IncTick();
  }
}

/**
  * @brief  This function is executed in case of error occurrence.
  * @retval None
  */
void Error_Handler(void)
{
  /* USER CODE BEGIN Error_Handler_Debug */
	/* User can add his own implementation to report the HAL error return state */
	__disable_irq();
	while (1)
	{
	}
  /* USER CODE END Error_Handler_Debug */
}
#ifdef USE_FULL_ASSERT
/**
  * @brief  Reports the name of the source file and the source line number
  *         where the assert_param error has occurred.
  * @param  file: pointer to the source file name
  * @param  line: assert_param error line source number
  * @retval None
  */
void assert_failed(uint8_t *file, uint32_t line)
{
  /* USER CODE BEGIN 6 */
	/* User can add his own implementation to report the file name and line number,
ex: printf("Wrong parameters value: file %s on line %d\r\n", file, line) */
  /* USER CODE END 6 */
}
#endif /* USE_FULL_ASSERT */

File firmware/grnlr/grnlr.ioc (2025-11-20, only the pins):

Mcu.UserName=STM32F446ZCTx
PA0-WKUP.GPIO_Label=VCP_TX
PA0-WKUP.Signal=UART4_TX
PA1.GPIO_Label=VCP_RX
PA1.Signal=UART4_RX
PA11.Signal=USB_OTG_FS_DM
PA12.Signal=USB_OTG_FS_DP
PA13.Signal=SYS_JTMS-SWDIO
PA14.Signal=SYS_JTCK-SWCLK
PA2.GPIO_Label=ENC_A
PA2.Signal=GPXTI2
PA3.GPIO_Label=ENC_B
PA3.Signal=GPIO_Input
PB10.Signal=I2C2_SCL
PB11.Signal=I2C2_SDA
PB3.Signal=SYS_JTDO-SWO
PB5.Signal=FMC_SDCKE1
PB6.Signal=FMC_SDNE1
PB7.GPIO_Label=SD_DETECT
PB7.Signal=GPIO_Input
PB8.Signal=I2C1_SCL
PB9.Signal=I2C1_SDA
PC0.Signal=FMC_SDNWE
PC1.Signal=ADCx_IN11
PC10.Signal=SDIO_D2
PC11.Signal=SDIO_D3
PC12.Signal=SDIO_CK
PC14-OSC32_IN.Signal=RCC_OSC32_IN
PC15-OSC32_OUT.Signal=RCC_OSC32_OUT
PC2.Signal=ADCx_IN12
PC3.GPIO_Label=LED
PC3.Signal=GPIO_Output
PC8.Signal=SDIO_D0
PC9.Signal=SDIO_D1
PD0.Signal=FMC_D2_DA2
PD1.Signal=FMC_D3_DA3
PD10.Signal=FMC_D15_DA15
PD12.GPIO_Label=OLED_RESET
PD12.Signal=GPIO_Output
PD13.GPIO_Label=ENC_PB
PD13.Signal=GPXTI13
PD14.Signal=FMC_D0_DA0
PD15.Signal=FMC_D1_DA1
PD2.Signal=SDIO_CMD
PD8.Signal=FMC_D13_DA13
PD9.Signal=FMC_D14_DA14
PE0.Signal=FMC_NBL0
PE1.Signal=FMC_NBL1
PE10.Signal=FMC_D7_DA7
PE11.Signal=FMC_D8_DA8
PE12.Signal=FMC_D9_DA9
PE13.Signal=FMC_D10_DA10
PE14.Signal=FMC_D11_DA11
PE15.Signal=FMC_D12_DA12
PE2.Signal=SAI1_MCLK_A
PE3.Signal=SAI1_SD_B
PE4.Signal=SAI1_FS_A
PE5.Signal=SAI1_SCK_A
PE6.Signal=SAI1_SD_A
PE7.Signal=FMC_D4_DA4
PE8.Signal=FMC_D5_DA5
PE9.Signal=FMC_D6_DA6
PF0.Signal=FMC_A0
PF1.Signal=FMC_A1
PF10.Signal=ADC3_IN8
PF11.Signal=FMC_SDNRAS
PF12.Signal=FMC_A6
PF13.Signal=FMC_A7
PF14.Signal=FMC_A8
PF15.Signal=FMC_A9
PF2.Signal=FMC_A2
PF3.Signal=FMC_A3
PF4.Signal=FMC_A4
PF5.Signal=FMC_A5
PF6.Signal=ADC3_IN4
PF7.Signal=ADC3_IN5
PF8.Signal=ADC3_IN6
PF9.Signal=ADC3_IN7
PG0.Signal=FMC_A10
PG1.Signal=FMC_A11
PG15.Signal=FMC_SDNCAS
PG4.Signal=FMC_A14_BA0
PG5.Signal=FMC_A15_BA1
PG8.Signal=FMC_SDCLK
PH0-OSC_IN.Signal=RCC_OSC_IN
PH1-OSC_OUT.Signal=RCC_OSC_OUT

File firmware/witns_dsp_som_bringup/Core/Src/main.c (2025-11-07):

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
/* Includes ------------------------------------------------------------------*/
#include "main.h"
#include "adc.h"
#include "dma.h"
#include "fatfs.h"
#include "i2c.h"
#include "sai.h"
#include "sdio.h"
#include "usart.h"
#include "usb_otg.h"
#include "gpio.h"
#include "fmc.h"

/* USER CODE BEGIN Includes */
#include <stdio.h>
#include "sgtl5000.h"
#include "ssd1306.h"
#include "ssd1306_tests.h"
#include "ssd1306_fonts.h"
/* USER CODE END Includes */

/* USER CODE BEGIN PD */
#define SAI_TX_BUFFER_LENGTH (480*2)
#define SAI_RX_BUFFER_LENGTH (480*2)
/* USER CODE END PD */


void SystemClock_Config(void);
void PeriphCommonClock_Config(void);
/* USER CODE BEGIN PFP */
static const unsigned char garfield_128x64 [] = {
		0x00, 0x00, 0x00, 0x00, 0x00, 0x00, 0x00, 0x00, 0x00, 0x00, 0x00, 0x00, 0x00, 0x00, 0x00, 0x00,
		0x00, 0x00, 0x00, 0x00, 0x00, 0x07, 0xFF, 0x00, 0x00, 0x00, 0x00, 0x00, 0x00, 0x00, 0x00, 0x00,
		0x00, 0x00, 0x00, 0x00, 0x00, 0x1F, 0xFF, 0xF8, 0x7F, 0xE0, 0x00, 0x00, 0x00, 0x00, 0x00, 0x00,
		0x00, 0x00, 0x00, 0x00, 0x00, 0x3F, 0xFF, 0xCF, 0xFF, 0xFE, 0x00, 0x00, 0x00, 0x00, 0x00, 0x00,
		0x00, 0x00, 0x00, 0x00, 0x00, 0x3F, 0xFB, 0xE3, 0xFF, 0xF3, 0x80, 0x00, 0x00, 0x00, 0x00, 0x00,
		0x00, 0x00, 0x00, 0x00, 0x00, 0x3F, 0xC0, 0xF3, 0xFF, 0xF8, 0xE0, 0x00, 0x00, 0x00, 0x00, 0x00,
		0x00, 0x00, 0x00, 0x00, 0x00, 0x1F, 0x00, 0x1F, 0xD9, 0xFC, 0x38, 0x00, 0x00, 0x00, 0x00, 0x00,
		0x00, 0x00, 0x00, 0x00, 0x00, 0x0D, 0x00, 0x0F, 0x00, 0x1E, 0x0C, 0x00, 0x00, 0x00, 0x00, 0x00,
		0x00, 0x00, 0x00, 0x00, 0x0C, 0x0C, 0x0E, 0x1F, 0xF8, 0x03, 0x04, 0x00, 0x00, 0x00, 0x00, 0x00,
		0x00, 0x00, 0x00, 0x00, 0x03, 0x87, 0xF0, 0x07, 0x00, 0x01, 0x86, 0x00, 0x00, 0x00, 0x00, 0x00,
		0x00, 0x00, 0x00, 0x00, 0x18, 0x3B, 0x80, 0x18, 0x00, 0x30, 0xC3, 0x00, 0x00, 0x00, 0x00, 0x00,
		0x00, 0x00, 0x00, 0x00, 0x00, 0xFE, 0x00, 0x60, 0x00, 0x18, 0xC3, 0x01, 0xC0, 0x00, 0x00, 0x00,
		0x00, 0x00, 0x00, 0x00, 0x3F, 0xFC, 0x01, 0x80, 0x00, 0x0F, 0xC3, 0x8F, 0xC0, 0x00, 0x00, 0x00,
		0x00, 0x00, 0x00, 0x00, 0x07, 0xF0, 0x03, 0x00, 0x00, 0x0C, 0x07, 0xF0, 0x00, 0x00, 0x00, 0x00,
		0x00, 0x00, 0x00, 0x00, 0x0F, 0xE0, 0x0C, 0x00, 0x00, 0x0C, 0x07, 0xFF, 0xF8, 0x00, 0x00, 0x00,
		0x00, 0x00, 0x00, 0x00, 0x38, 0xC0, 0x18, 0x00, 0x00, 0x08, 0x0F, 0xFF, 0xF0, 0x00, 0x00, 0x00,
		0x00, 0x00, 0x00, 0x00, 0x71, 0x80, 0x30, 0x00, 0x00, 0x08, 0x0F, 0xFC, 0xFC, 0x00, 0x00, 0x00,
		0x00, 0x00, 0x00, 0x00, 0xF7, 0x00, 0x60, 0x00, 0x00, 0x18, 0x3F, 0xFE, 0x00, 0x00, 0x00, 0x00,
		0x00, 0x00, 0x00, 0x01, 0xFF, 0x00, 0x60, 0x00, 0x00, 0x18, 0x7F, 0xFE, 0x00, 0x00, 0x00, 0x00,
		0x00, 0x00, 0x00, 0x03, 0xFF, 0x00, 0xC0, 0x00, 0x00, 0x30, 0xFF, 0x1F, 0x00, 0x00, 0x00, 0x00,
		0x00, 0x00, 0x00, 0x03, 0x83, 0xE0, 0xC0, 0x00, 0x00, 0x60, 0x00, 0x03, 0x00, 0x00, 0x00, 0x00,
		0x00, 0x00, 0x00, 0x07, 0x03, 0x1F, 0xFF, 0xFF, 0xFF, 0xC0, 0x00, 0x03, 0x80, 0x00, 0x00, 0x00,
		0x00, 0x00, 0x00, 0x0E, 0x01, 0x00, 0xE7, 0xC0, 0x03, 0x80, 0x00, 0x0F, 0x80, 0x00, 0x00, 0x00,
		0x00, 0x00, 0x00, 0x0F, 0x01, 0x80, 0xE0, 0x00, 0x06, 0x00, 0x00, 0xFF, 0x80, 0x00, 0x00, 0x00,
		0x00, 0x00, 0x00, 0x0F, 0x83, 0x7F, 0xF0, 0x00, 0x38, 0x00, 0x26, 0xFF, 0x80, 0x00, 0x00, 0x00,
		0x00, 0x00, 0x00, 0x0F, 0xDC, 0x18, 0x1F, 0x87, 0xE0, 0x00, 0x26, 0xEF, 0x80, 0x00, 0x00, 0x00,
		0x00, 0x00, 0x00, 0x0F, 0xB8, 0x0E, 0x18, 0x00, 0x30, 0x00, 0x04, 0xCF, 0x80, 0x00, 0x00, 0x00,
		0x00, 0x00, 0x00, 0x0F, 0x30, 0x0F, 0xC0, 0x00, 0x18, 0x00, 0x00, 0x8F, 0x80, 0x00, 0x00, 0x00,
		0x00, 0x00, 0x00, 0x07, 0x30, 0x38, 0x70, 0x00, 0x18, 0x00, 0x00, 0x0F, 0x00, 0x00, 0x00, 0x00,
		0x00, 0x00, 0x00, 0x07, 0x18, 0x00, 0x1F, 0x00, 0x18, 0x3B, 0x80, 0x0E, 0x00, 0x00, 0x00, 0x00,
		0x00, 0x00, 0x00, 0x03, 0x8E, 0x00, 0x03, 0x80, 0x70, 0x1F, 0xF8, 0x1C, 0x00, 0x00, 0x00, 0x00,
		0x00, 0x00, 0x00, 0x01, 0xFF, 0x80, 0x00, 0x03, 0xE0, 0x1F, 0xFF, 0xF8, 0x00, 0x00, 0x00, 0x00,
		0x00, 0x00, 0x00, 0x00, 0x7F, 0x86, 0x00, 0x3F, 0x1F, 0x07, 0xFF, 0xE0, 0x00, 0x00, 0x00, 0x00,
		0x00, 0x00, 0x00, 0x00, 0x0F, 0xC3, 0x00, 0x00, 0x3F, 0x01, 0xFF, 0x80, 0x00, 0x00, 0x00, 0x00,
		0x00, 0x00, 0x00, 0x00, 0x01, 0xFF, 0x80, 0x00, 0x3F, 0xC7, 0xFC, 0x00, 0x00, 0x00, 0x00, 0x00,
		0x00, 0x00, 0x00, 0x00, 0x00, 0x73, 0xE0, 0x07, 0xFF, 0xFF, 0xF8, 0x00, 0x00, 0x00, 0x00, 0x00,
		0x00, 0x00, 0x00, 0x00, 0x00, 0xC0, 0x00, 0x07, 0xC0, 0x3F, 0xF8, 0x00, 0x00, 0x00, 0x00, 0x00,
		0x00, 0x00, 0x00, 0x00, 0x03, 0x00, 0x00, 0x00, 0x00, 0x3F, 0xF8, 0x00, 0x00, 0x00, 0x00, 0x00,
		0x00, 0x00, 0x00, 0x00, 0x0E, 0x00, 0x00, 0x00, 0x00, 0x3E, 0xF8, 0x00, 0x00, 0x00, 0x00, 0x00,
		0x00, 0x00, 0x00, 0x00, 0x18, 0x00, 0x00, 0x00, 0x00, 0xA4, 0xF0, 0x00, 0x00, 0x00, 0x00, 0x00,
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
};
/* USER CODE END PFP */

/* USER CODE BEGIN 0 */
int __io_putchar(int chr)
{
	HAL_UART_Transmit(&huart4, (uint8_t *)&chr, 1, HAL_MAX_DELAY);
	return chr;
}

FMC_SDRAM_CommandTypeDef command;
#define REFRESH_COUNT       ((uint32_t)0x056A)   /* SDRAM refresh counter (90MHz SDRAM clock) */
#define SDRAM_BANK_ADDR                 ((uint32_t)0xD0000000)

/* #define SDRAM_MEMORY_WIDTH            FMC_SDRAM_MEM_BUS_WIDTH_8 */
#define SDRAM_MEMORY_WIDTH            FMC_SDRAM_MEM_BUS_WIDTH_16

/* #define SDCLOCK_PERIOD                   FMC_SDRAM_CLOCK_PERIOD_2 */
#define SDCLOCK_PERIOD                FMC_SDRAM_CLOCK_PERIOD_3

#define SDRAM_TIMEOUT     ((uint32_t)0xFFFF)

#define SDRAM_MODEREG_BURST_LENGTH_1             ((uint16_t)0x0000)
#define SDRAM_MODEREG_BURST_LENGTH_2             ((uint16_t)0x0001)
#define SDRAM_MODEREG_BURST_LENGTH_4             ((uint16_t)0x0002)
#define SDRAM_MODEREG_BURST_LENGTH_8             ((uint16_t)0x0004)
#define SDRAM_MODEREG_BURST_TYPE_SEQUENTIAL      ((uint16_t)0x0000)
#define SDRAM_MODEREG_BURST_TYPE_INTERLEAVED     ((uint16_t)0x0008)
#define SDRAM_MODEREG_CAS_LATENCY_2              ((uint16_t)0x0020)
#define SDRAM_MODEREG_CAS_LATENCY_3              ((uint16_t)0x0030)
#define SDRAM_MODEREG_OPERATING_MODE_STANDARD    ((uint16_t)0x0000)
#define SDRAM_MODEREG_WRITEBURST_MODE_PROGRAMMED ((uint16_t)0x0000)
#define SDRAM_MODEREG_WRITEBURST_MODE_SINGLE     ((uint16_t)0x0200)
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

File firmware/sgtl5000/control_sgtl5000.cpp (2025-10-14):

/* Audio Library for Teensy 3.X
 * Copyright (c) 2014, Paul Stoffregen, paul@pjrc.com
 *
 * Development of this audio library was funded by PJRC.COM, LLC by sales of
 * Teensy and Audio Adaptor boards.  Please support PJRC's efforts to develop
 * open source software by purchasing Teensy or other PJRC products.
 *
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
 * THE SOFTWARE IS PROVIDED "AS IS", WITHOUT WARRANTY OF ANY KIND, EXPRESS OR
 * IMPLIED, INCLUDING BUT NOT LIMITED TO THE WARRANTIES OF MERCHANTABILITY,
 * FITNESS FOR A PARTICULAR PURPOSE AND NONINFRINGEMENT. IN NO EVENT SHALL THE
 * AUTHORS OR COPYRIGHT HOLDERS BE LIABLE FOR ANY CLAIM, DAMAGES OR OTHER
 * LIABILITY, WHETHER IN AN ACTION OF CONTRACT, TORT OR OTHERWISE, ARISING FROM,
 * OUT OF OR IN CONNECTION WITH THE SOFTWARE OR THE USE OR OTHER DEALINGS IN
 * THE SOFTWARE.
 */

#include <Arduino.h>
#include "control_sgtl5000.h"
#include "Wire.h"

#define CHIP_ID				0x0000
// 15:8 PARTID		0xA0 - 8 bit identifier for SGTL5000
// 7:0  REVID		0x00 - revision number for SGTL5000.

#define CHIP_DIG_POWER			0x0002
// 6	ADC_POWERUP	1=Enable, 0=disable the ADC block, both digital & analog,
// 5	DAC_POWERUP	1=Enable, 0=disable the DAC block, both analog and digital
// 4	DAP_POWERUP	1=Enable, 0=disable the DAP block
// 1	I2S_OUT_POWERUP	1=Enable, 0=disable the I2S data output
// 0	I2S_IN_POWERUP	1=Enable, 0=disable the I2S data input

#define CHIP_CLK_CTRL			0x0004
// 5:4	RATE_MODE	Sets the sample rate mode. MCLK_FREQ is still specified
//			relative to the rate in SYS_FS
//				0x0 = SYS_FS specifies the rate
//				0x1 = Rate is 1/2 of the SYS_FS rate
//				0x2 = Rate is 1/4 of the SYS_FS rate
//				0x3 = Rate is 1/6 of the SYS_FS rate
// 3:2	SYS_FS		Sets the internal system sample rate (default=2)
//				0x0 = 32 kHz
//				0x1 = 44.1 kHz
//				0x2 = 48 kHz
//				0x3 = 96 kHz
// 1:0	MCLK_FREQ	Identifies incoming SYS_MCLK frequency and if the PLL should be used
//				0x0 = 256*Fs
//				0x1 = 384*Fs
//				0x2 = 512*Fs
//				0x3 = Use PLL
//				The 0x3 (Use PLL) setting must be used if the SYS_MCLK is not
//				a standard multiple of Fs (256, 384, or 512). This setting can
//				also be used if SYS_MCLK is a standard multiple of Fs.
//				Before this field is set to 0x3 (Use PLL), the PLL must be
//				powered up by setting CHIP_ANA_POWER->PLL_POWERUP and
//				CHIP_ANA_POWER->VCOAMP_POWERUP.  Also, the PLL dividers must
//				be calculated based on the external MCLK rate and
//				CHIP_PLL_CTRL register must be set (see CHIP_PLL_CTRL register
//				description details on how to calculate the divisors).

#define CHIP_I2S_CTRL			0x0006
// 8	SCLKFREQ	Sets frequency of I2S_SCLK when in master mode (MS=1). When in slave
//			mode (MS=0), this field must be set appropriately to match SCLK input
//			rate.
//				0x0 = 64Fs
//				0x1 = 32Fs - Not supported for RJ mode (I2S_MODE = 1)
// 7	MS		Configures master or slave of I2S_LRCLK and I2S_SCLK.
//				0x0 = Slave: I2S_LRCLK an I2S_SCLK are inputs
//				0x1 = Master: I2S_LRCLK and I2S_SCLK are outputs
//				NOTE: If the PLL is used (CHIP_CLK_CTRL->MCLK_FREQ==0x3),
//				the SGTL5000 must be a master of the I2S port (MS==1)
// 6	SCLK_INV	Sets the edge that data (input and output) is clocked in on for I2S_SCLK
//				0x0 = data is valid on rising edge of I2S_SCLK
//				0x1 = data is valid on falling edge of I2S_SCLK
// 5:4	DLEN		I2S data length (default=1)
//				0x0 = 32 bits (only valid when SCLKFREQ=0),
//					not valid for Right Justified Mode
//				0x1 = 24 bits (only valid when SCLKFREQ=0)
//				0x2 = 20 bits
//				0x3 = 16 bits
// 3:2	I2S_MODE	Sets the mode for the I2S port
//				0x0 = I2S mode or Left Justified (Use LRALIGN to select)
//				0x1 = Right Justified Mode
//				0x2 = PCM Format A/B
//				0x3 = RESERVED
// 1	LRALIGN		I2S_LRCLK Alignment to data word. Not used for Right Justified mode
//				0x0 = Data word starts 1 I2S_SCLK delay after I2S_LRCLK
//					transition (I2S format, PCM format A)
//				0x1 = Data word starts after I2S_LRCLK transition (left
//					justified format, PCM format B)
// 0	LRPOL		I2S_LRCLK Polarity when data is presented.
//				0x0 = I2S_LRCLK = 0 - Left, 1 - Right
//				1x0 = I2S_LRCLK = 0 - Right, 1 - Left
//				The left subframe should be presented first regardless of
//				the setting of LRPOL.

#define CHIP_SSS_CTRL			0x000A
// 14	DAP_MIX_LRSWAP	DAP Mixer Input Swap
//				0x0 = Normal Operation
//				0x1 = Left and Right channels for the DAP MIXER Input are swapped.
// 13	DAP_LRSWAP	DAP Mixer Input Swap
//				0x0 = Normal Operation
//				0x1 = Left and Right channels for the DAP Input are swapped
// 12	DAC_LRSWAP	DAC Input Swap
//				0x0 = Normal Operation
//				0x1 = Left and Right channels for the DAC are swapped
// 10	I2S_LRSWAP	I2S_DOUT Swap
//				0x0 = Normal Operation
//				0x1 = Left and Right channels for the I2S_DOUT are swapped
// 9:8	DAP_MIX_SELECT	Select data source for DAP mixer
//				0x0 = ADC
//				0x1 = I2S_IN
//				0x2 = Reserved
//				0x3 = Reserved
// 7:6	DAP_SELECT	Select data source for DAP
//				0x0 = ADC
//				0x1 = I2S_IN
//				0x2 = Reserved
//				0x3 = Reserved
// 5:4	DAC_SELECT	Select data source for DAC (default=1)
//				0x0 = ADC
//				0x1 = I2S_IN
//				0x2 = Reserved
//				0x3 = DAP
// 1:0	I2S_SELECT	Select data source for I2S_DOUT
//				0x0 = ADC
//				0x1 = I2S_IN
//				0x2 = Reserved
//				0x3 = DAP

#define CHIP_ADCDAC_CTRL		0x000E
// 13	VOL_BUSY_DAC_RIGHT Volume Busy DAC Right
//				0x0 = Ready
//				0x1 = Busy - This indicates the channel has not reached its
//					programmed volume/mute level
// 12	VOL_BUSY_DAC_LEFT  Volume Busy DAC Left
//				0x0 = Ready
//				0x1 = Busy - This indicates the channel has not reached its
//					programmed volume/mute level
// 9	VOL_RAMP_EN	Volume Ramp Enable (default=1)
//				0x0 = Disables volume ramp. New volume settings take immediate
//					effect without a ramp
//				0x1 = Enables volume ramp
//				This field affects DAC_VOL. The volume ramp effects both
//				volume settings and mute When set to 1 a soft mute is enabled.
// 8	VOL_EXPO_RAMP	Exponential Volume Ramp Enable
//				0x0 = Linear ramp over top 4 volume octaves
//				0x1 = Exponential ramp over full volume range
//				This bit only takes effect if VOL_RAMP_EN is 1.
// 3	DAC_MUTE_RIGHT	DAC Right Mute (default=1)
//				0x0 = Unmute
//				0x1 = Muted
//				If VOL_RAMP_EN = 1, this is a soft mute.
// 2	DAC_MUTE_LEFT	DAC Left Mute (default=1)
//				0x0 = Unmute
//				0x1 = Muted
//				If VOL_RAMP_EN = 1, this is a soft mute.
// 1	ADC_HPF_FREEZE	ADC High Pass Filter Freeze
//				0x0 = Normal operation
//				0x1 = Freeze the ADC high-pass filter offset register.  The
//				offset continues to be subtracted from the ADC data stream.
// 0	ADC_HPF_BYPASS	ADC High Pass Filter Bypass
//				0x0 = Normal operation
//				0x1 = Bypassed and offset not updated
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

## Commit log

2024-02-26 added kicad library
2024-02-26 started the project
    [dsp_som.kicad_pcb, dsp_som.kicad_sch]
2024-03-04 1st attempt at routing the SDRAM
    [dsp_som.kicad_pcb, dsp_som.kicad_sch]
2024-03-05 routing 1st version
    [dsp_som.kicad_pcb, dsp_som.kicad_sch]
2024-03-06 silkscreen again
    [dsp_som.kicad_pcb]
2024-03-07 gnd vias
    [dsp_som.kicad_pcb, dsp_som.kicad_sch]
2024-03-12 Change SGTL5000 model due to obsolescence
    [dsp_som.kicad_pcb, dsp_som.kicad_sch]
2024-03-29 fabrication files
    [dsp_som-B_Cu.gbr, dsp_som-B_Mask.gbr, dsp_som-B_Paste.gbr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]
2024-03-29 added JLCJLCJLCJLC
    [dsp_som-B_Cu.gbr, dsp_som-B_Mask.gbr, dsp_som-B_Paste.gbr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]
2024-03-29 solder paste clearance 10%
    [dsp_som-B_Cu.gbr, dsp_som-B_Mask.gbr, dsp_som-B_Paste.gbr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]
2025-10-10 carryer board for dsp som
    [analog_back-end.kicad_sch, analog_front-end.kicad_sch, carry.kicad_pcb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]
2025-10-11 routing carry board
    [carry.kicad_pcb, carry.kicad_sch, dsp_som_slot.kicad_sch]
2025-10-12 carry board silkscreen
    [carry.kicad_pcb]
2025-10-13 fab files for carry board
    [carry-B_Cu.gbr, carry-B_Mask.gbr, carry-Edge_Cuts.gbr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]
2025-11-05 test display with carry board
2025-11-05 3d models
    [carry.step, dsp_som.step]
2025-11-07 sgtl5000 driver not tested
2025-11-12 SD DMA with audio OK
2025-11-14 added i2c dma to ssd1306

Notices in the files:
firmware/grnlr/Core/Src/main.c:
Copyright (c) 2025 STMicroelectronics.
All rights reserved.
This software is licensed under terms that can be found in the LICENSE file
